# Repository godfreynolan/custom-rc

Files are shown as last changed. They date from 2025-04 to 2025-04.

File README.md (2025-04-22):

This repo contains code, PCB files, and 3D design files for the custom RC prototype.

- `code/gamepad/gamepad.ino` is the Arduino code for reading joystick/button inputs and sending them as USB HID device (e.g. gamepad, mouse) inputs to the main device.
- `pcbs/` contains Kicad design files for the left and right custom PCBs
  - `pcbs/left/` is the left PCB
    - `pcbs/left/outputs.zip` contains Gerber and drill files for ordering the left PCB
  - `pcbs/right/` is the right PCB
    - `pcbs/right/outputs.zip` contains Gerber and drill files for ordering the right PCB
  - Libraries are provided for the joystick and Arduino Pro Micro schematic/layout
- `3d/RC.3mf` is the 3D design file for the 3D printable housing
  - The design is split into many pieces that should be printed separately. All prints can fit on a 22cm x 22cm build plate
  - All parts should be printed facing down (as in, if all parts were being printed together, the whole devie would be oriented with the screen on the build plate)
  - The source project can be found at https://cad.onshape.com/documents/00098938a704a2da40e66fbd/w/5194b559f3115a3992b58aa5/e/1a9a5ca69a7348197c5309db

## Instructions for Ordering Custom PCBs
1. Go to https://cart.jlcpcb.com/quote
2. CLick "Add gerber file" and upload one of `pcbs/left/outputs.zip` or `pcbs/right/outputs.zip` for the left and right PCBs respectively
3. Select a quantity (minimum is 5)
4. Change PCB thickness to 1.2mm
5. Change surface finish to Lead Free HASL
6. Everything else can be left as the default
7. Save to cart and repeat the above steps to add the PCB for the other side to your order before you checkout

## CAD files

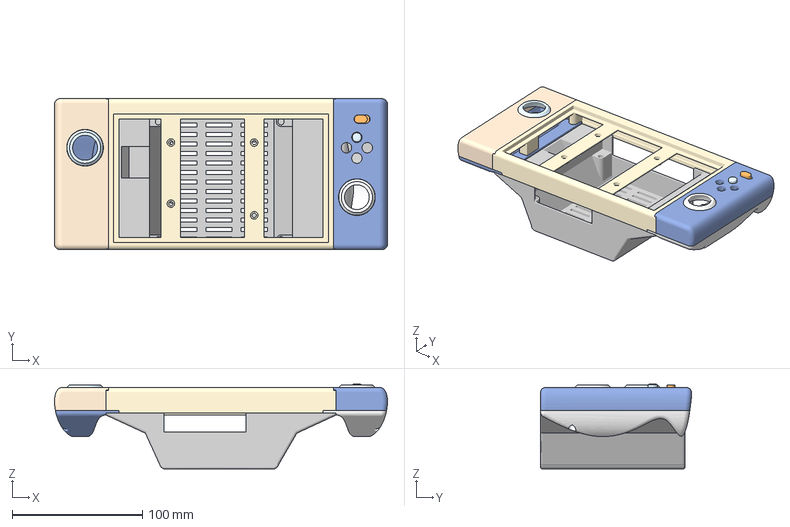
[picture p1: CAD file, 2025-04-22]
3d/RC.3mf
256.1 x 116.2 x 65.3 mm
Right Grip
Center
Right
Right Switch
Left
Right Stick
Left Stick
Back Center
Button
Right Grip Spacer x 6
Left Grip Spacer
Left Grip Space x 3
Left Grip

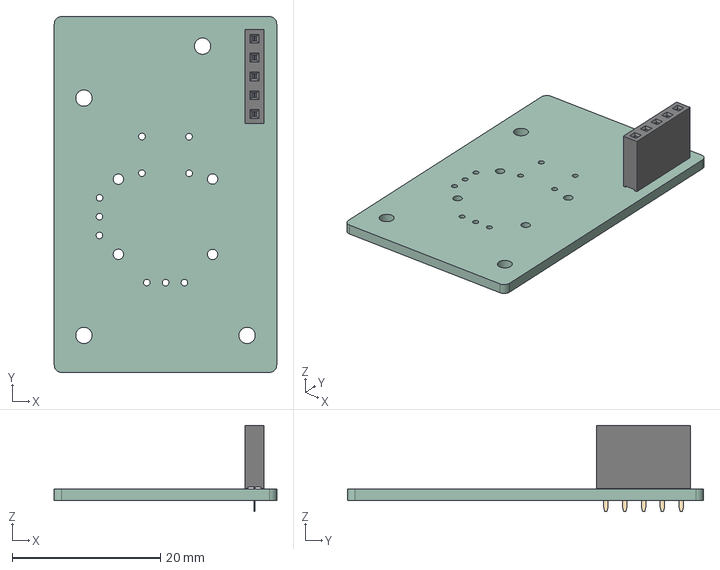
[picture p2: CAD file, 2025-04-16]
pcbs/left/left.step
30.0 x 48.0 x 11.6 mm
PinSocket_1x05_P2.54mm_Vertical
left_PCB

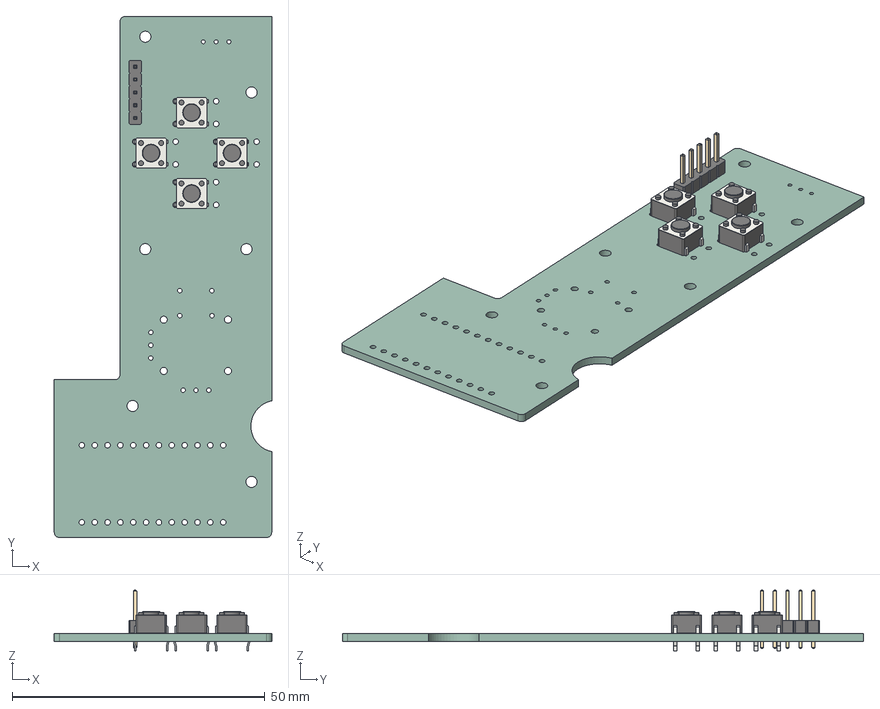
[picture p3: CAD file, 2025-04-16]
pcbs/right/right.step
43.0 x 103.0 x 12.0 mm
SW_PUSH_6mm_H4.3mm x 4
PinHeader_1x05_P2.54mm_Vertical
right_PCB

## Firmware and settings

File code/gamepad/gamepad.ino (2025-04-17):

#include <avr/power.h>
#include <EEPROM.h>

#include "Mouse.h"
#include "Keyboard.h"

#include "Joystick.h" // https://github.com/MHeironimus/ArduinoJoystickLibrary

// Pin mappings
#define JOYSTICK_LEFT_X_PIN A7
#define JOYSTICK_LEFT_Y_PIN A6
#define JOYSTICK_LEFT_BUTTON_PIN 7

#define JOYSTICK_RIGHT_X_PIN A0
#define JOYSTICK_RIGHT_Y_PIN A2
#define JOYSTICK_RIGHT_BUTTON_PIN 2

#define BUTTON_BOTTOM_PIN 14
#define BUTTON_RIGHT_PIN 10
#define BUTTON_TOP_PIN 16
#define BUTTON_LEFT_PIN 15

#define SWITCH_PIN 9

// HID button indices
#define BUTTON_BOTTOM_INDEX 0
#define BUTTON_RIGHT_INDEX 1
#define BUTTON_TOP_INDEX 3
#define BUTTON_LEFT_INDEX 4

// Input settings
#define JOYSTICK_RANGE 127
#define JOYSTICK_CENTER_ANALOG_READING 512
#define DEADZONE 12
#define MOUSE_SENSITIVITY 12
#define SCROLL_SENSITIVITY 3
#define SCROLL_DELAY 5

// EEPROM memory address for calibration data
#define CALIBRATION_LEFT_X_EEPROM_ADDR 0
#define CALIBRATION_LEFT_Y_EEPROM_ADDR sizeof(JoystickCalibration)
#define CALIBRATION_RIGHT_X_EEPROM_ADDR (2 * sizeof(JoystickCalibration))
#define CALIBRATION_RIGHT_Y_EEPROM_ADDR (3 * sizeof(JoystickCalibration))

typedef struct {
    int min = 0;
    int center = 512;
    int max = 1023;
} JoystickCalibration;

JoystickCalibration calibration_left_x = {};
JoystickCalibration calibration_left_y = {};
JoystickCalibration calibration_right_x = {};
JoystickCalibration calibration_right_y = {};

Joystick_ Joystick(JOYSTICK_DEFAULT_REPORT_ID,JOYSTICK_TYPE_GAMEPAD,
    5, 0,                  // Button Count, Hat Switch Count
    true, true, false,     // X and Y, but no Z Axis
    true, true, false,     // Rx, Ry, no Rz
    false, false,          // No rudder or throttle
    false, false, false    // No accelerator, brake, or steering
); 

unsigned int scroll_delay_counter = SCROLL_DELAY;

/*
 * Like Arduino's map function but ensures values below center are mapped below
 * center and values above center are mapped above center.
 */
int centered_map(int input, int input_min, int input_center, int input_max, int output_min, int output_center, int output_max) {
    if (input < input_center) {
        return map(input, input_min, input_center, output_min, output_center);
    } else if (input > input_center) {
        return map(input, input_center, input_max, output_center, output_max);
    } else {
        return output_center;
    }
}

/* Convert an analog reading from a joystick to a HID joystick input.
*/
int analog_joystick_to_joystick(int analog_reading, JoystickCalibration calibration) {
    if (abs(analog_reading - calibration.center) < DEADZONE) {
        return 0;
    }
    return centered_map(analog_reading, calibration.min, calibration.center, calibration.max, -JOYSTICK_RANGE, 0, JOYSTICK_RANGE);
}

/* Convert an analog reading from a joystick to a HID mouse input.
*/
int analog_joystick_to_mouse(int analog_reading, JoystickCalibration calibration) {
    if (abs(analog_reading - calibration.center) < DEADZONE) {
        return 0;
    }
    return centered_map(analog_reading, calibration.min, calibration.center, calibration.max, -MOUSE_SENSITIVITY, 0, MOUSE_SENSITIVITY);
}

/* Convert an analog reading from a joystick to a HID mouse wheel input.
*/
int analog_joystick_to_scrollwheel(int analog_reading, JoystickCalibration calibration) {
    if (abs(analog_reading - calibration.center) < DEADZONE) {
        return 0;
    }
    return centered_map(analog_reading, calibration.min, calibration.center, calibration.max, -SCROLL_SENSITIVITY, 0, SCROLL_SENSITIVITY);
}

void wait_until_released(uint8_t pin) {
    while(!digitalRead(pin));
}

void wait_until_pressed(uint8_t pin) {
    while(digitalRead(pin));
}

void calibration_debounce() {
    delay(250);
}

/* Calibration sequence for left joystick
 */
void calibrate_left(JoystickCalibration* calibration_x, JoystickCalibration* calibration_y) {
    Serial.println("Left calibration started");
    // center
    calibration_x->center = analogRead(JOYSTICK_LEFT_X_PIN);;
    calibration_y->center = analogRead(JOYSTICK_LEFT_Y_PIN);;
    wait_until_released(JOYSTICK_RIGHT_BUTTON_PIN);
    calibration_debounce();

    // y max
    Serial.println("Move left stick to top and press right stick");
    wait_until_pressed(JOYSTICK_RIGHT_BUTTON_PIN);
    calibration_y->max = analogRead(JOYSTICK_LEFT_Y_PIN);
    wait_until_released(JOYSTICK_RIGHT_BUTTON_PIN);
    calibration_debounce();

    // y min
    Serial.println("Move left stick to bottom and press right stick");
    wait_until_pressed(JOYSTICK_RIGHT_BUTTON_PIN);
    calibration_y->min = analogRead(JOYSTICK_LEFT_Y_PIN);
    wait_until_released(JOYSTICK_RIGHT_BUTTON_PIN);
    calibration_debounce();

    // x min
    Serial.println("Move left stick to left and press right stick");
    wait_until_pressed(JOYSTICK_RIGHT_BUTTON_PIN);
    calibration_x->min = analogRead(JOYSTICK_LEFT_X_PIN);
    wait_until_released(JOYSTICK_RIGHT_BUTTON_PIN);
    calibration_debounce();

    // x max
    Serial.println("Move left stick to right and press right stick");
    wait_until_pressed(JOYSTICK_RIGHT_BUTTON_PIN);
    calibration_x->max = analogRead(JOYSTICK_LEFT_X_PIN);
    wait_until_released(JOYSTICK_RIGHT_BUTTON_PIN);
    calibration_debounce();

    EEPROM.put(CALIBRATION_LEFT_X_EEPROM_ADDR, *calibration_x);
    EEPROM.put(CALIBRATION_LEFT_Y_EEPROM_ADDR, *calibration_y);
}

void calibrate_right(JoystickCalibration* calibration_x, JoystickCalibration* calibration_y) {
    // center
    Serial.println("Right calibration started");
    calibration_x->center = analogRead(JOYSTICK_RIGHT_X_PIN);;
    calibration_y->center = analogRead(JOYSTICK_RIGHT_Y_PIN);;
    wait_until_released(JOYSTICK_LEFT_BUTTON_PIN);
    calibration_debounce();

    // y max
    Serial.println("Move right stick to top and press left stick");
    wait_until_pressed(JOYSTICK_LEFT_BUTTON_PIN);
    calibration_y->max = analogRead(JOYSTICK_RIGHT_Y_PIN);
    wait_until_released(JOYSTICK_LEFT_BUTTON_PIN);
    calibration_debounce();

    // y min
    Serial.println("Move right stick to bottom and press left stick");
    wait_until_pressed(JOYSTICK_LEFT_BUTTON_PIN);
    calibration_y->min = analogRead(JOYSTICK_RIGHT_Y_PIN);
    wait_until_released(JOYSTICK_LEFT_BUTTON_PIN);
    calibration_debounce();

    // x min
    Serial.println("Move right stick to left and press left stick");
    wait_until_pressed(JOYSTICK_LEFT_BUTTON_PIN);
    calibration_x->min = analogRead(JOYSTICK_RIGHT_X_PIN);
    wait_until_released(JOYSTICK_LEFT_BUTTON_PIN);
    calibration_debounce();

    // x max
    Serial.println("Move right stick to right and press left stick");
    wait_until_pressed(JOYSTICK_LEFT_BUTTON_PIN);
    calibration_x->max = analogRead(JOYSTICK_RIGHT_X_PIN);
    wait_until_released(JOYSTICK_LEFT_BUTTON_PIN);
    calibration_debounce();

    EEPROM.put(CALIBRATION_RIGHT_X_EEPROM_ADDR, *calibration_x);
    EEPROM.put(CALIBRATION_RIGHT_Y_EEPROM_ADDR, *calibration_y);
}

void setup() {
    // clock_prescale_set(clock_div_2);

    Serial.begin(9600);

    // Initialize pins
    pinMode(JOYSTICK_RIGHT_X_PIN, INPUT);
    pinMode(JOYSTICK_RIGHT_Y_PIN, INPUT);
    pinMode(JOYSTICK_RIGHT_BUTTON_PIN, INPUT_PULLUP);

    pinMode(JOYSTICK_LEFT_X_PIN, INPUT);
    pinMode(JOYSTICK_LEFT_Y_PIN, INPUT);
    pinMode(JOYSTICK_LEFT_BUTTON_PIN, INPUT_PULLUP);

    pinMode(BUTTON_BOTTOM_PIN, INPUT_PULLUP);
    pinMode(BUTTON_RIGHT_PIN, INPUT_PULLUP);
    pinMode(BUTTON_TOP_PIN, INPUT_PULLUP);
    pinMode(BUTTON_LEFT_PIN, INPUT_PULLUP);

    pinMode(SWITCH_PIN, INPUT_PULLUP);

    // Set intended output range for sticks
    Joystick.setXAxisRange(-JOYSTICK_RANGE, JOYSTICK_RANGE);
    Joystick.setYAxisRange(-JOYSTICK_RANGE, JOYSTICK_RANGE);
    Joystick.setRxAxisRange(-JOYSTICK_RANGE, JOYSTICK_RANGE);
    Joystick.setRyAxisRange(-JOYSTICK_RANGE, JOYSTICK_RANGE);

    // Read calibration data. If this is the first time using this code, this 
    // data will be garbage. The sticks won't work properly until they are
    // calibrated.
    EEPROM.get(CALIBRATION_LEFT_X_EEPROM_ADDR, calibration_left_x);
    EEPROM.get(CALIBRATION_LEFT_Y_EEPROM_ADDR, calibration_left_y);
    EEPROM.get(CALIBRATION_RIGHT_X_EEPROM_ADDR, calibration_right_x);
    EEPROM.get(CALIBRATION_RIGHT_Y_EEPROM_ADDR, calibration_right_y);

    Joystick.begin(false);
    Mouse.begin();
    Keyboard.begin();
}

void loop() {
    // Enter calibration sequence if either of the stick buttons are pushed.
    if (!digitalRead(JOYSTICK_RIGHT_BUTTON_PIN)) {
        calibrate_left(&calibration_left_x, &calibration_left_y);
    } else if (!digitalRead(JOYSTICK_LEFT_BUTTON_PIN)) {
        calibrate_right(&calibration_right_x, &calibration_right_y);
    }

    const bool mouse_mode = digitalRead(SWITCH_PIN);
    if (mouse_mode) {
        const int left_x = analog_joystick_to_mouse(analogRead(JOYSTICK_LEFT_X_PIN), calibration_left_x);
        const int left_y = -analog_joystick_to_mouse(analogRead(JOYSTICK_LEFT_Y_PIN), calibration_left_y);
        
        // Things will scroll too fast even if right_y == 1 if we send this 
        // every update. Instead, we'll only send scroll values once every
        // SCROLL_DELAY updates.
        int right_y; 
        if (scroll_delay_counter >= SCROLL_DELAY) {
            right_y = -analog_joystick_to_scrollwheel(analogRead(JOYSTICK_RIGHT_Y_PIN), calibration_right_y);
            scroll_delay_counter = 0;
        } else {
            right_y = 0;
        }
        if (scroll_delay_counter < SCROLL_DELAY) {
            scroll_delay_counter++;
        }

        Mouse.move(left_x, left_y, -right_y);

        const bool button_bottom = !digitalRead(BUTTON_BOTTOM_PIN);
        const bool button_right = !digitalRead(BUTTON_RIGHT_PIN);
        //const bool button_top = !digitalRead(BUTTON_TOP_PIN);
        //const bool button_left = !digitalRead(BUTTON_LEFT_PIN);

        if (button_bottom) {
            Mouse.press(MOUSE_LEFT);
        } else {
            Mouse.release(MOUSE_LEFT);
        }
        if (button_right) {
            Mouse.press(MOUSE_RIGHT);
        } else {
            Mouse.release(MOUSE_RIGHT);
        }

    } else {
        const int left_x = analog_joystick_to_joystick(analogRead(JOYSTICK_LEFT_X_PIN), calibration_left_x);
        const int left_y = -analog_joystick_to_joystick(analogRead(JOYSTICK_LEFT_Y_PIN), calibration_left_y);
        Joystick.setXAxis(left_x);
        Joystick.setYAxis(left_y);

        const int right_x = analog_joystick_to_joystick(analogRead(JOYSTICK_RIGHT_X_PIN), calibration_right_x);
        const int right_y = -analog_joystick_to_joystick(analogRead(JOYSTICK_RIGHT_Y_PIN), calibration_right_y);
        Joystick.setRxAxis(right_x);
        Joystick.setRyAxis(right_y);

        const bool button_bottom = !digitalRead(BUTTON_BOTTOM_PIN);
        const bool button_right = !digitalRead(BUTTON_RIGHT_PIN);
        const bool button_top = !digitalRead(BUTTON_TOP_PIN);
        const bool button_left = !digitalRead(BUTTON_LEFT_PIN);
        Joystick.setButton(BUTTON_BOTTOM_INDEX, button_bottom);
        Joystick.setButton(BUTTON_RIGHT_INDEX, button_right);
        Joystick.setButton(BUTTON_TOP_INDEX, button_top);
        Joystick.setButton(BUTTON_LEFT_INDEX, button_left);

        Joystick.sendState();
    }
    delay(10);
}

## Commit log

2025-04-22 Add 3d design files
    [RC.3mf]
2025-04-22 Add PCB ordering instructions
